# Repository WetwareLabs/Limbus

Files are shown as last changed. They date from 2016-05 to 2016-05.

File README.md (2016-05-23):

Limbus is a family of low power wireless nodes. 

It is named "Limbus" because thay reside in the interface between man and machine (or between changing environment and the more stagnant building). 

The first published sensor is Model D (a coin cell powered motion sensor), but few others are being developed.

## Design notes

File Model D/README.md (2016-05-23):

# Limbus - Model D

## A low power wireless motion sensor powered by coin cells

### Hardware used:

- Atmega328p
- Panasonic PIR sensor EKMB1101113
- RFM69W wireless module
- SI7021 temperature and humidity sensor
- Watchdog TPL5010
- Flash chip W25X40CL
- CR2450 (soldered in) or CR2032 (battery holder)
- WS2812B RGB led

[Please see the disucssion here.](https://lowpowerlab.com/forum/index.php?topic=1913)

----

### Optional components:

- C2 OR C1 can be omitted (other 10 uF cap is there just in case..)
- Y1 (resonator) can be omitted (works fine with the internal 8 Mhz resonator)
- Flash chip, R6, R15, R5, Q1 can be left out if wireless OTA updates are not wanted
- WS2812B led can be left out or replaced with normal led (with clever usage of existing WS2812B pads :)
- If temperature/humidity sensing is not needed, U2 and C7, R2, R3 can be left out. Also in this case the whole TPL5010 watchdog could be left out since no periodic transmissions are needed (unless you want battery levels transmitted)

-----

## Changelog

Revision 01 files are here only for reference, please use rev 02. 

Note that the updated layout has not yet been tested by me (I have only rev 01 PCBs, where corrections are done with jumper wires), but since modifications are quite minor, I don't anticipate any problems.

Changes in revision 02:

- Removed unnecessary Q2, R9 and R8. Power the WS2812B instead from A1 pin
- Removed unnecessary R14,R13,C6. Read VCC instead measuring 1.1V reference against VCC.
- Swapped through-hole reset switch to SMD one
- Swapped bottom VCC/GND connectors to route GND plane more efficiently (jumper wire or reset switch not necessary)
- PIR output wired to D7 (instead of A7, since it doesn't even have interrupt capability :) 
- Added R11 (100K) between PIR sensor GND and OUT for stability
- Added 100nF cap between PIR sensor GND and VCC (this may not be necessary and is not even in the datasheet, but added just in case..)
- Enlarged holes for CR2450 and partially isolated the GND pin from rest of the ground plane (to make it easier to de/re-solder the battery)
- Routed a connector also from D6 (in addition to D5)
- Other minor layout alterations

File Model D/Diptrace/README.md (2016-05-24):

## Diptrace schematics and PCB layout files for Limbus Model D

You can open these files directly in Diptrace, but to successfully edit them with correct work-flow requires that libraries are set up correctly, since many components contain references to my custom component library.

First copy the library files (components and patterns) from top level repository directory to your Diptrace Library directory.

Unfortunately the way Diptrace currently handles the references to libraries is that even if you set up these new libraries in Diptrace (via Library / Library Setup), every component in schematic and PCB layout file has a reference to the library file name and path individually. It can be tedious to change them by hand, so use this method:
- export schematic to Diptrace .asc
- with text editor change all "LibPath" references quickly with Find/Replace to correct filename and path
- import schematic again and save
- load PCB file and check that it references the correct schematic (File / Layout Information)
- then do File / Renew layout from Schematic

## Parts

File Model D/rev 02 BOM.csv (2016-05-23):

# | RefDes | Name | Value
1 | BT1 | BATT_HOLDER_RENATA_HU2032-LF
2 | BT2 | CR-2450/G1AN | 620 mAh
3 | C1 | CAP_0603 | 0.1uF
4 | C2 | CAP_1206 | 10 uF
5 | C3 | CAP_1206 | 10 uF
6 | C4 | CAP_0603 | 0.1uF
7 | C5 | CAP_0603 | 0.1uF
8 | C6 | CAP_0603 | 0.1 uF
9 | C7 | CAP_0603 | 0.1 uF
10 | C8 | CAP_0603 | 0.1 uF
11 | C9 | CAP_0603 | 0.1uF
12 | D1 | LED_0805
13 | J1 | TC2030-MCP-NL | ICSP
14 | J2 | TC2030-MCP-NL | FTDI
15 | Q1 | SI2333CD
16 | R1 | RES_0603 | 10k
17 | R2 | RES_0603 | 10k
18 | R3 | RES_0603 | 10k
19 | R4 | RES_0603 | 10K
20 | R5 | RES_0603 | 100
21 | R6 | RES_0603 | 10K
22 | R7 | RES_0603 | 330
23 | R10 | RES_0603 | 100
24 | R11 | RES_0603 | 100K
25 | R12 | RES_0603 | 1.2M
26 | R15 | RES_0603 | 10K
27 | R26 | RES_0603 | 6.8K for 1s period
28 | R28 | RES_0603 | 22K for 1s period
29 | S1 | TL3315NF100Q | RESET SWITCH
30 | U1 | ATMEGA168_TQFP
31 | U2 | SI7021-A20
32 | U3 | RFM69W
33 | U4 | W25X40CLSN
34 | U5 | EKMB1101113
35 | U6 | TPL5010
36 | U7 | WS2812B
37 | Y1 | CSTCEV

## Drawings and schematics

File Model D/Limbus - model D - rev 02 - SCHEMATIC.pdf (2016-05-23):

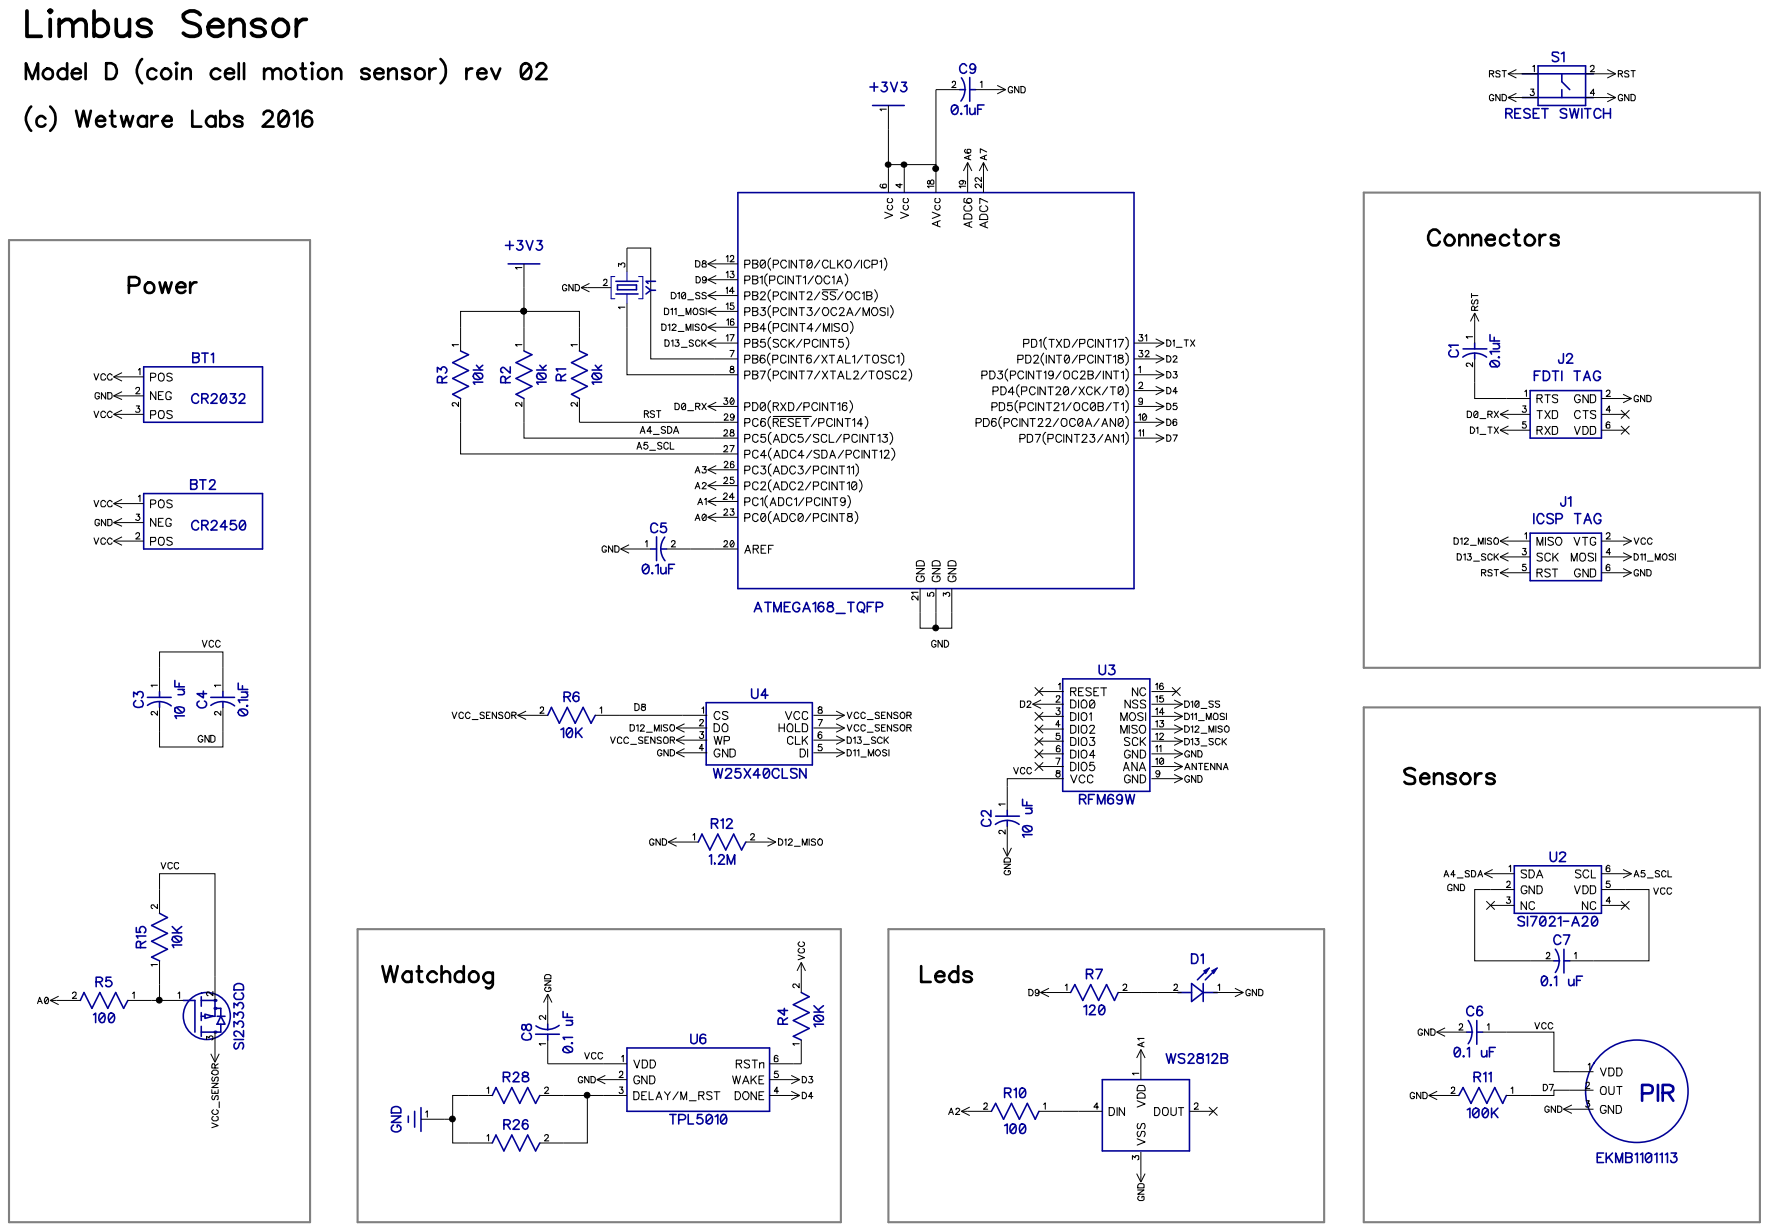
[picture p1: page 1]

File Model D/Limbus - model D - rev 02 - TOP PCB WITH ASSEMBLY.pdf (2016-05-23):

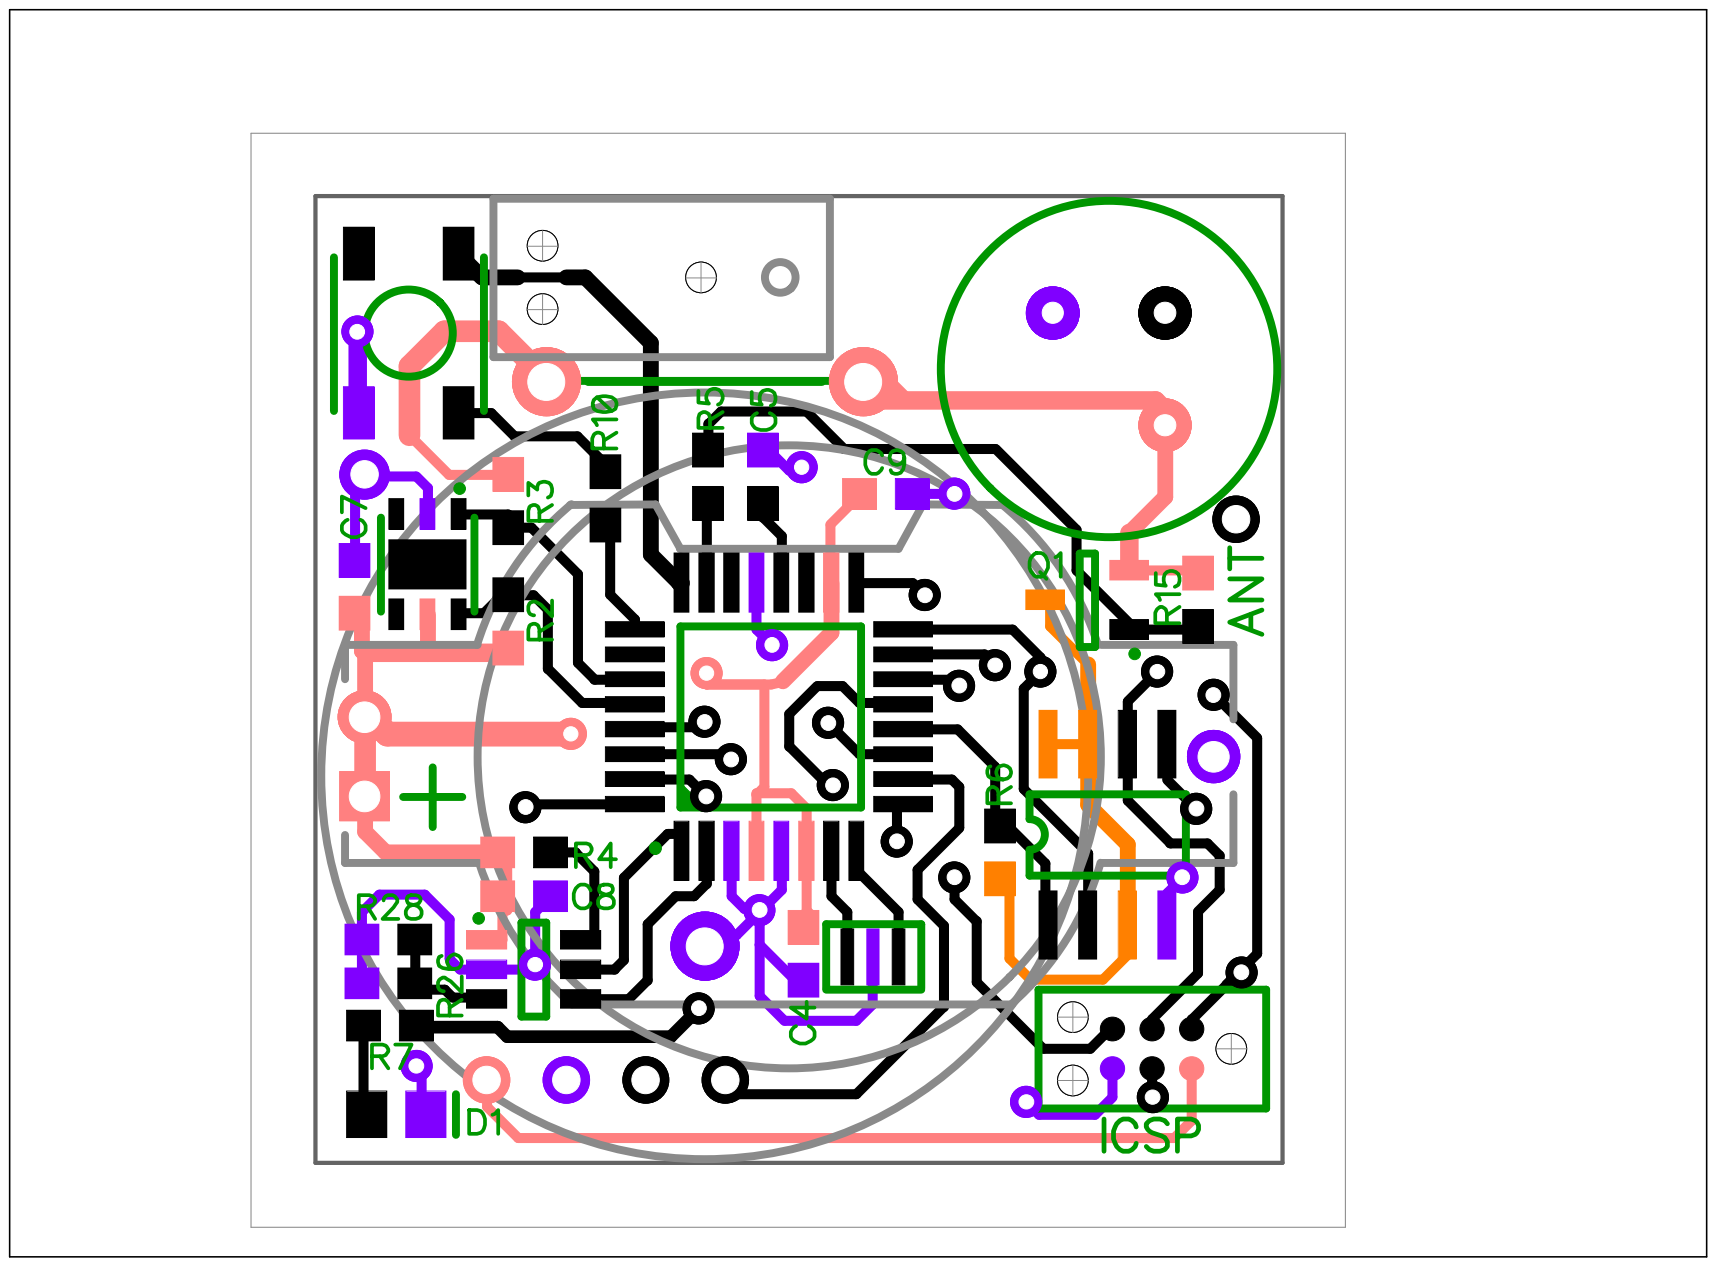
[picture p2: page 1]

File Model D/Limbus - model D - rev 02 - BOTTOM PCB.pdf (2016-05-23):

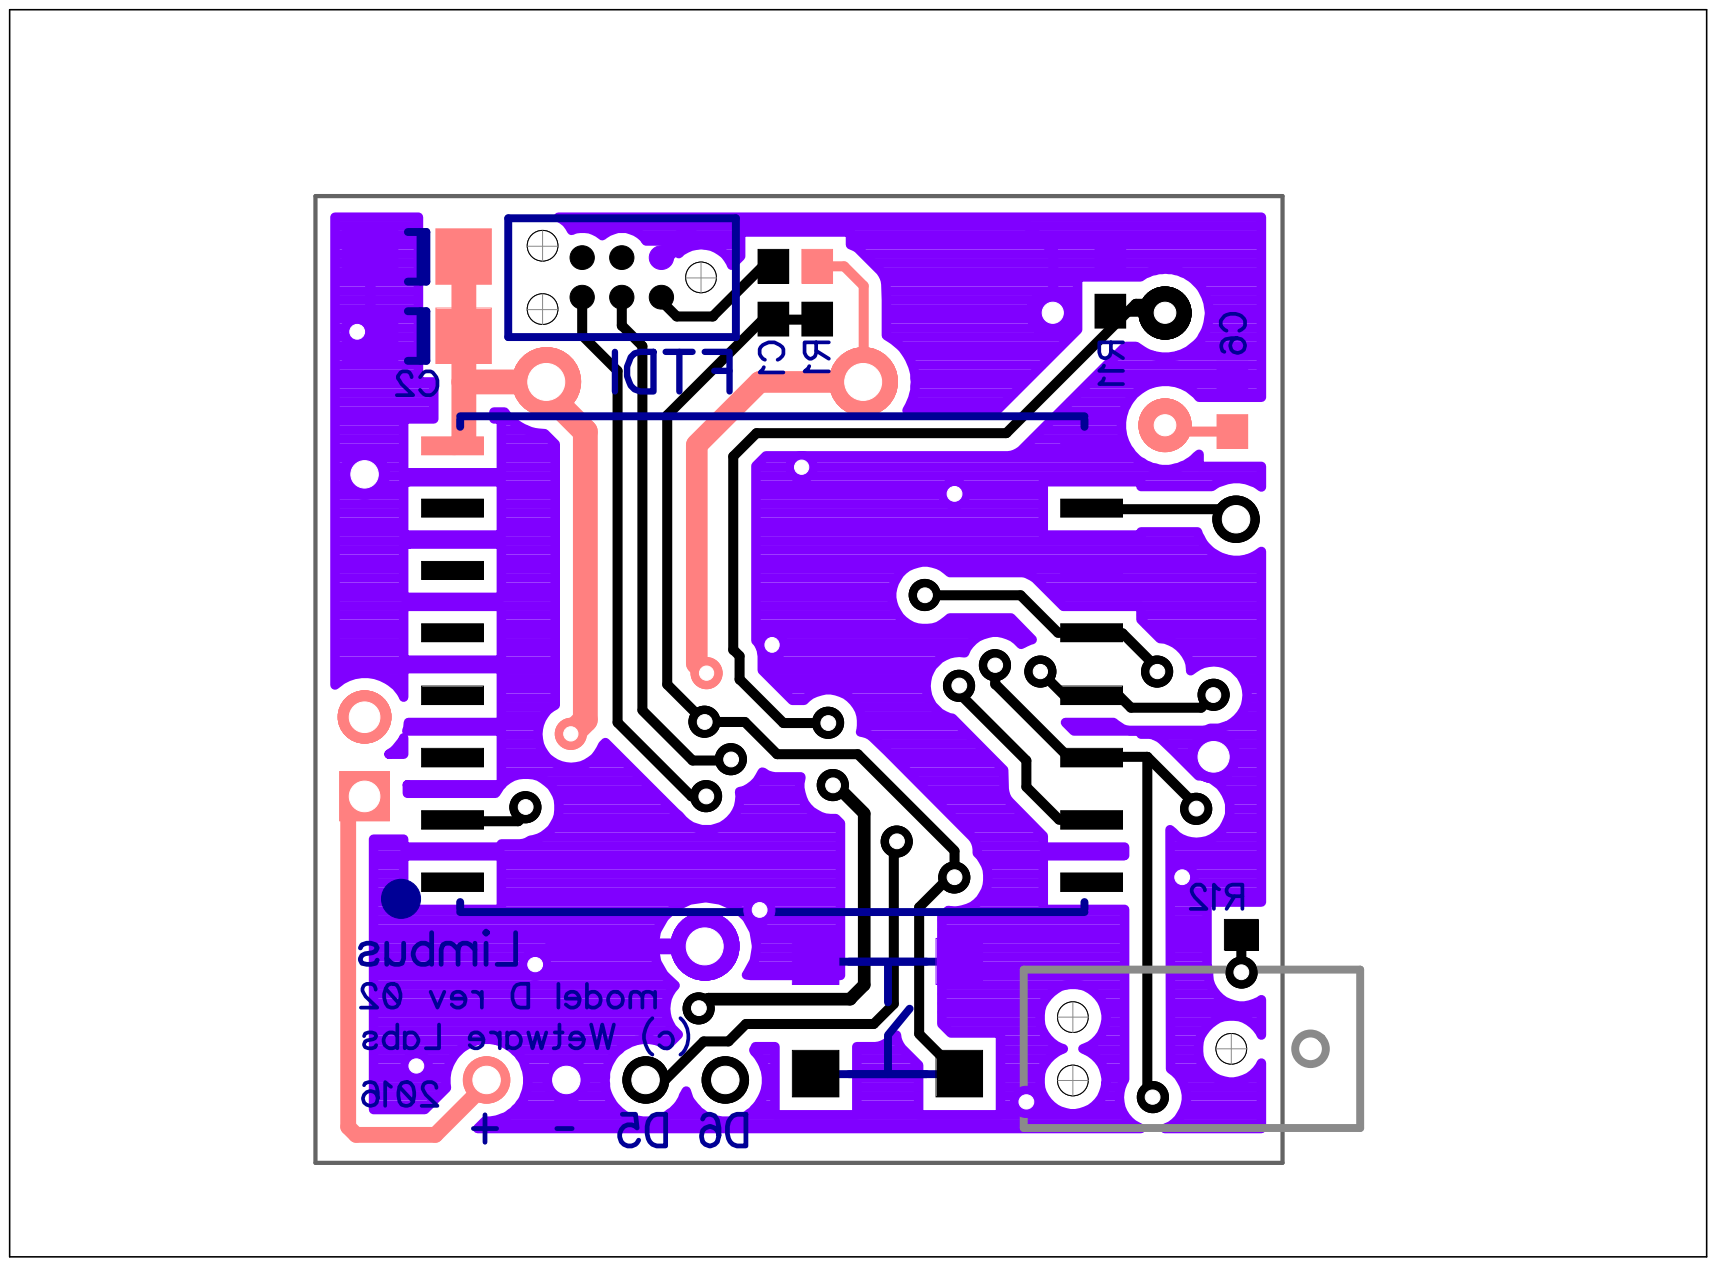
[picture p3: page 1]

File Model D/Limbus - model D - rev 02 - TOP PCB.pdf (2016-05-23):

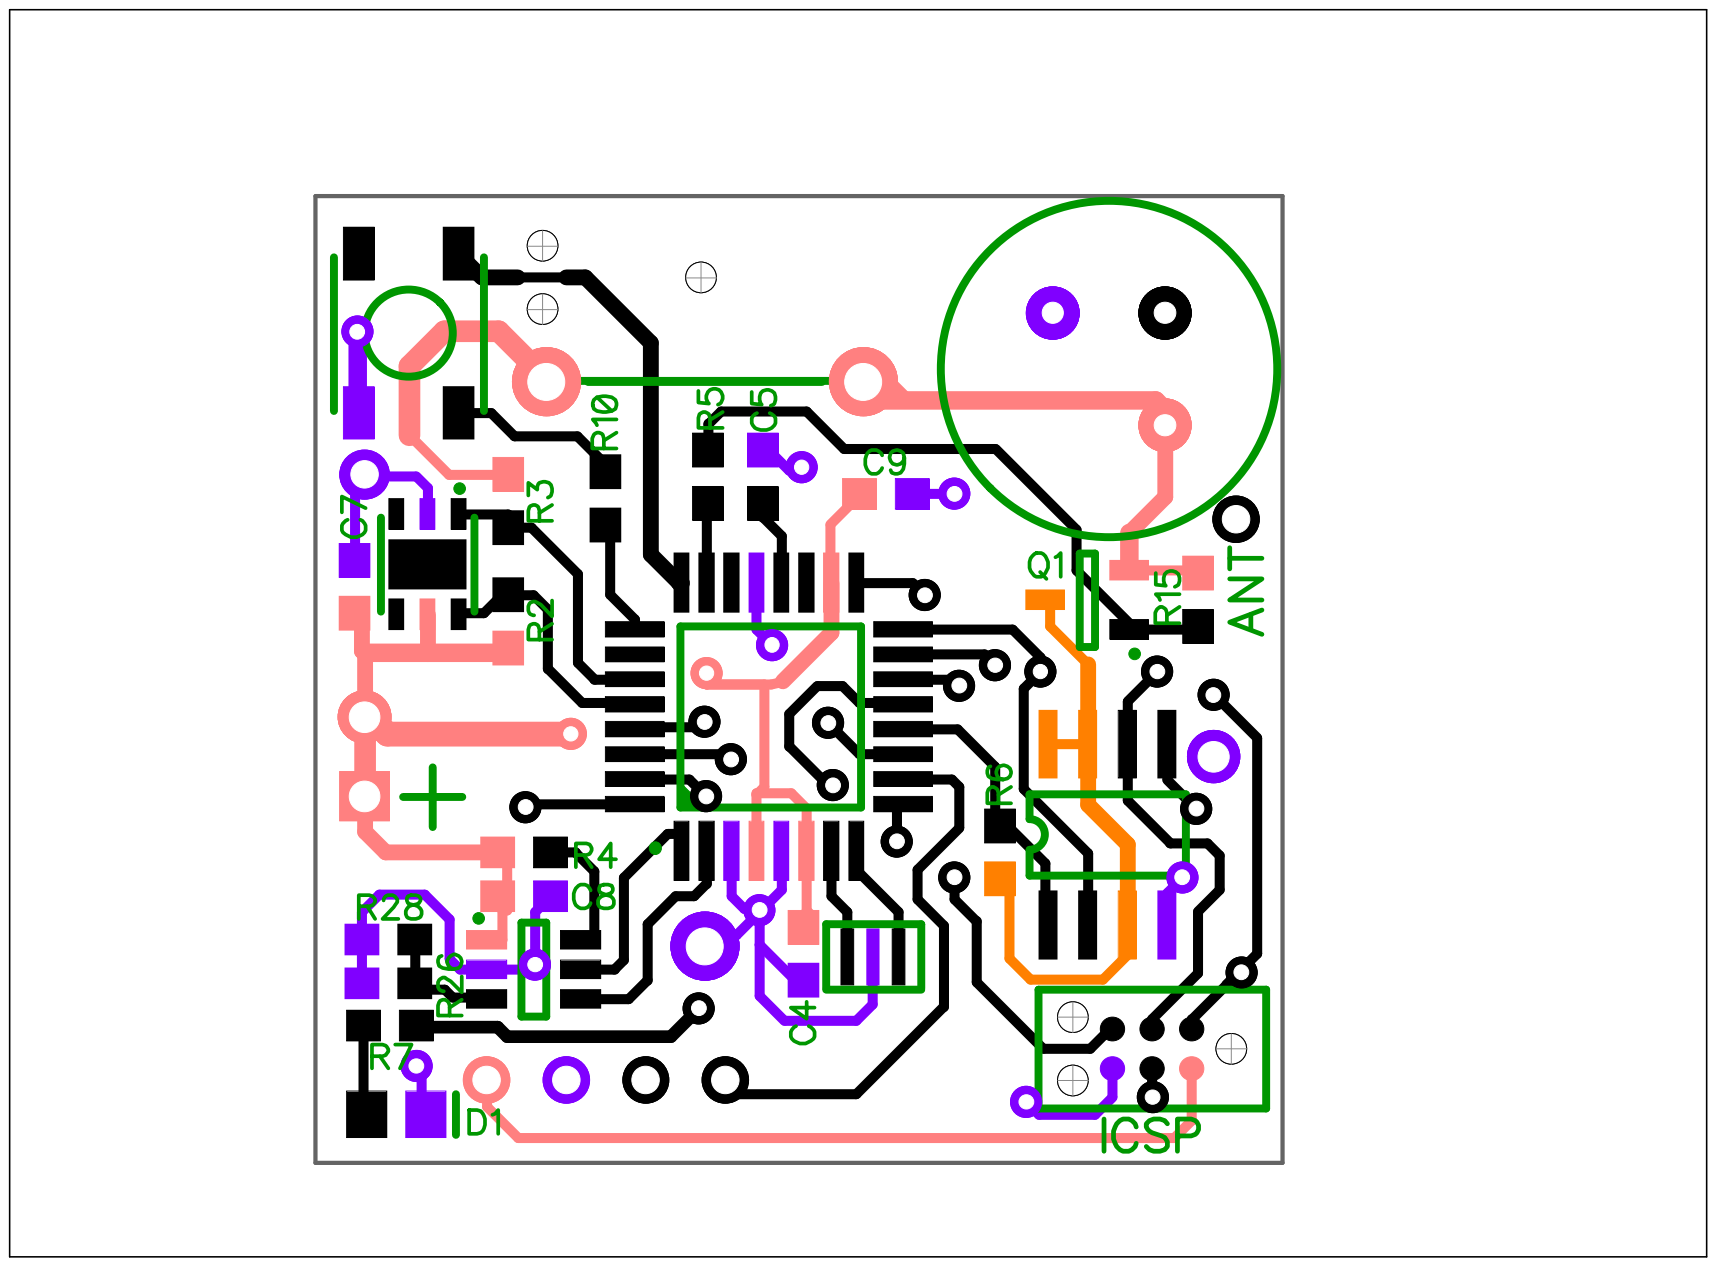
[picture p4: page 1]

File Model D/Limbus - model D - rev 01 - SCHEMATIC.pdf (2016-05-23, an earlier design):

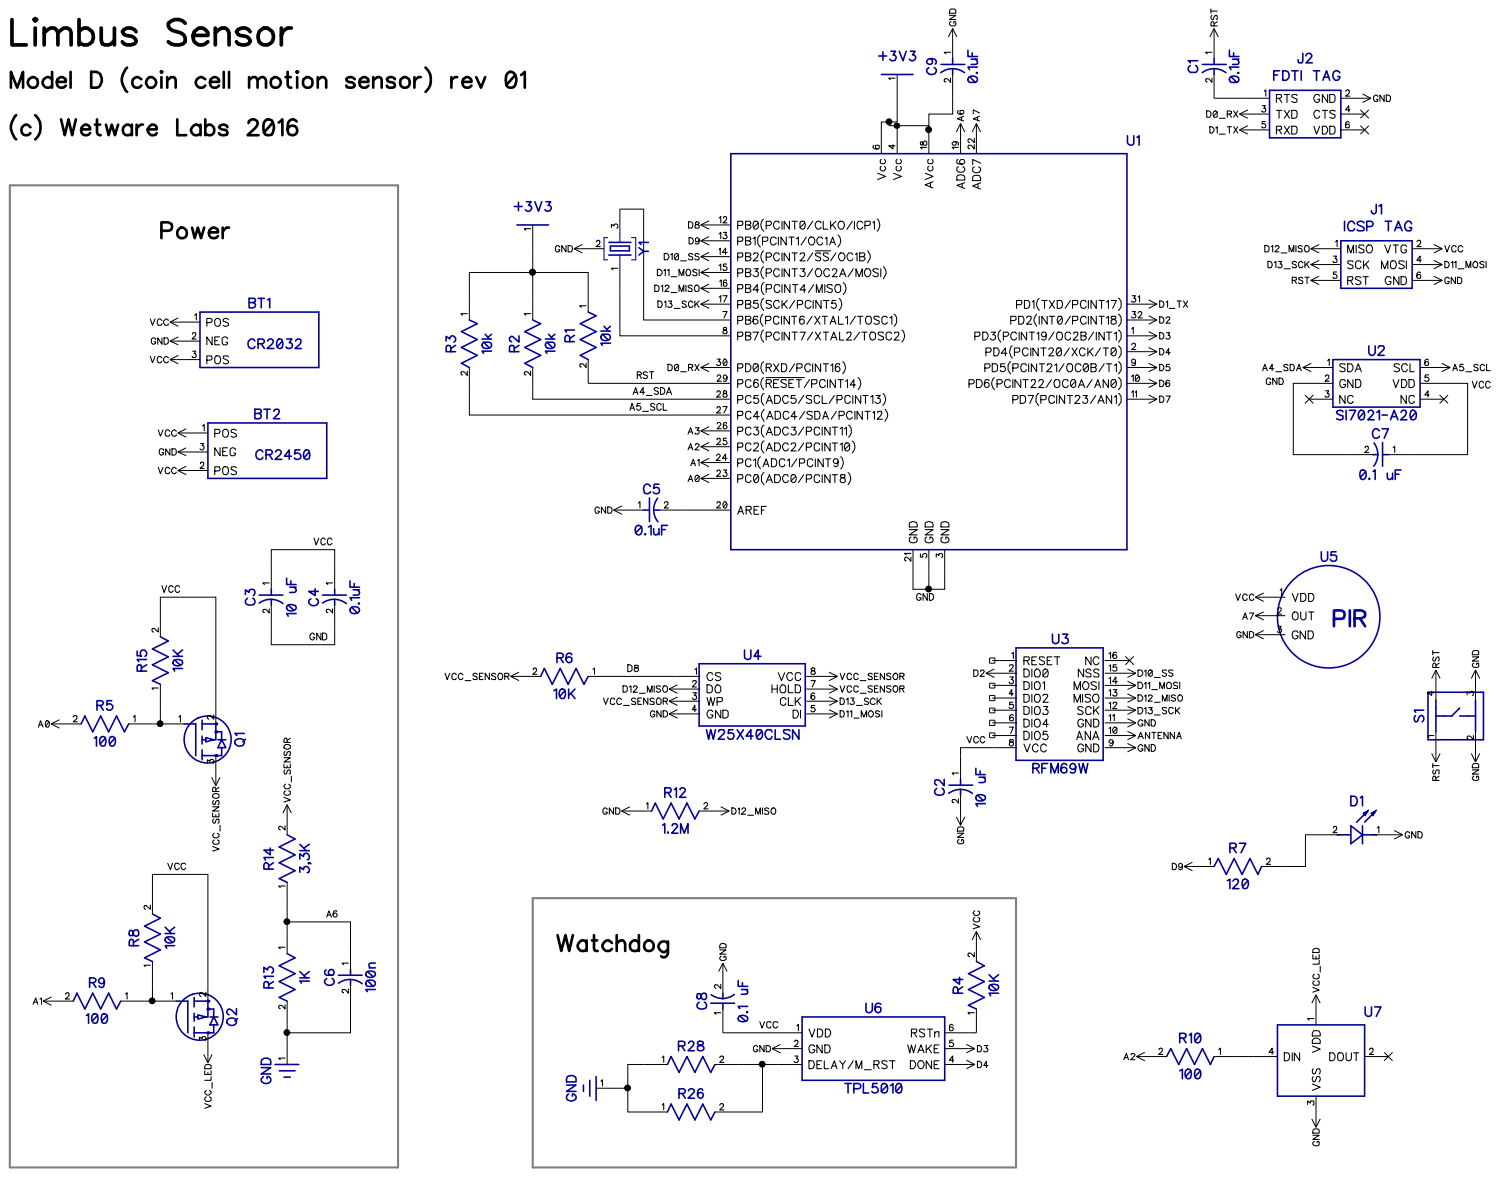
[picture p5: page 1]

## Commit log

2016-05-23 Updated readme Added BOM
    [rev 02 BOM.csv]
2016-05-24 Added Diptrace schematic, PCB layout and needed library files
